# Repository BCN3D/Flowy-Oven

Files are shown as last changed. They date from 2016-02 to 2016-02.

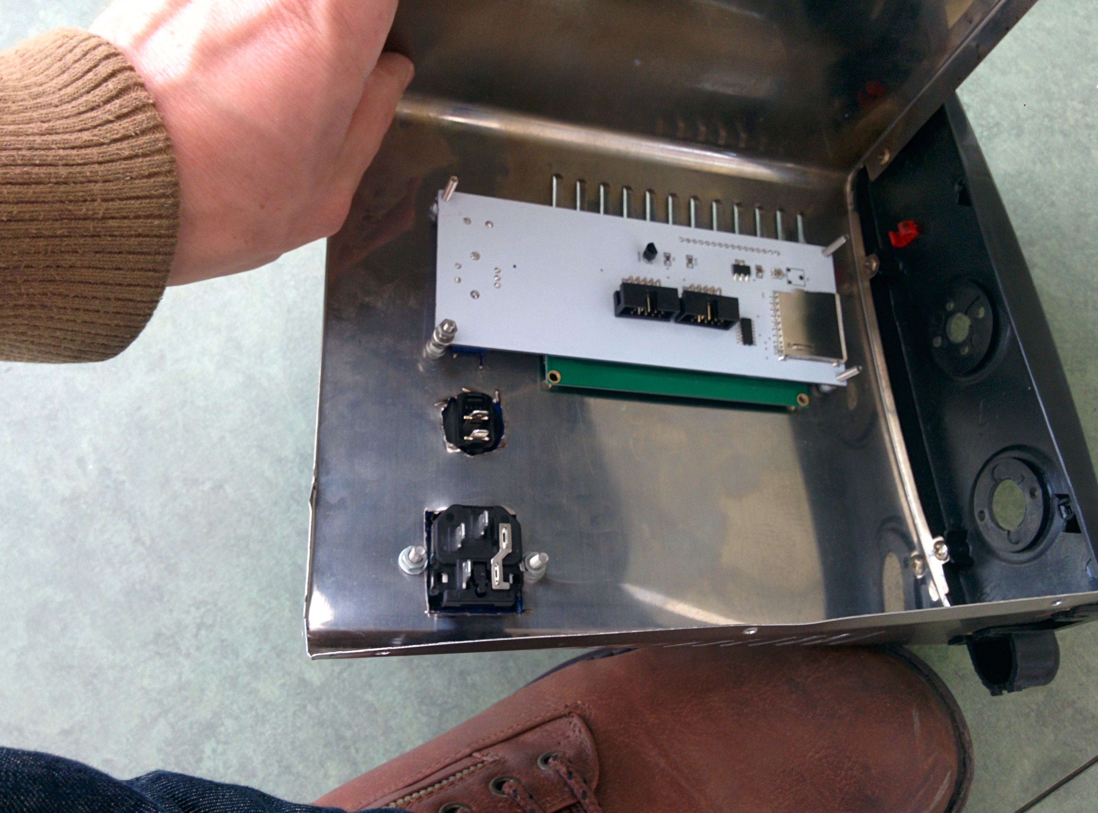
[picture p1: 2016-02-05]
img/IMG_20151126_135709.jpg

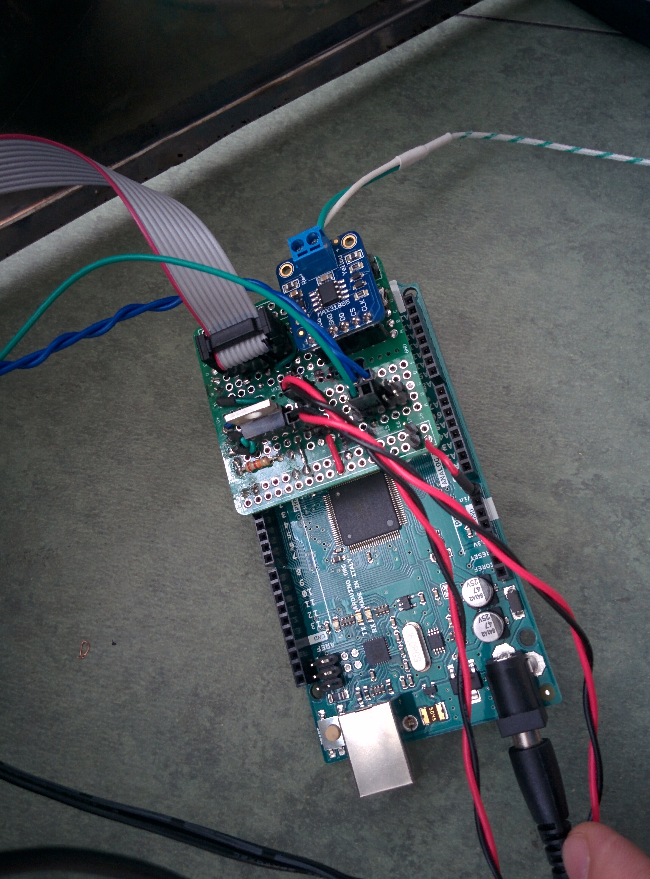
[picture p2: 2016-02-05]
img/IMG_20160113_123603.jpg

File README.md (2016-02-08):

# Flowy Oven
DIY Reflow oven for electronics prototyping.
Here @BCN3DTechnologies we prototype everything quite a lot, and electronics is not an exception.   
That's why we thought we needed a reflow oven. The professional ones are too expensive and we decided to make one by ourselves.   

This Reflow Oven is based on the following projects:
+ [Reflow Oven by Kevin Darrah](http://www.kevindarrah.com/download/arduino_code/ReflowOven_v1.ino)
+ [Reflow Oven by Ben Heck](https://www.youtube.com/watch?v=ckcHyMxqesM)

## Bill of Materials - BOM
+ Reclaimed standard home oven. Ours is about 1KW.
+ Arduino Mega 2560. We have a lot of them laying arround.
+ SSR. Solid State Relay.
+ 16x4 LCD Display with encoder to navigate.
+ Thermocouple breakout board. MAX31855 from adafruit.
+ 12V power supply
+ A fan for cooling the electronics and another to move hot air.
+ Main fused switch, cables and connectors.

## Documents
The following list explains what contains each folder.
+ **src:** where the `Arduino` code lives.
+ **Examples:** Here are also a few examples related to the LCD display and Thermocouple.
+ **Datasheets:** folder to store the Datasheets related to the project.
+ **img:** some pictures of the project.
+ **Printed Parts:** the `CAD` files of the printed parts that we've used to mount the system.

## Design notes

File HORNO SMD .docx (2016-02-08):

HORNO SMD

Descripción del proyecto

Para poder agilizar el proceso de prototipado de placas electrónicas en BCN3D Technologies, hemos decidido implementar nuestras propias herramientas de manera casera.

La primera de estas herramientas es un horno de reflujo. Este horno permite soldar todos los componentes a la vez habiendo colocado previamente todos los componentes encima de la pasta de soldadura.

El horno de reflujo está basado en un horno doméstico para calentar diferentes alimentos. Tiene una potencia de 1000W y dispone de selección de elementos calefactores y temporizador.

Funcionalidades y modificaciones

El horno no solo tiene que ser capaz de llegar a la suficiente temperatura para fundir la pasta de soldadura y soldar los componentes si no que debe de hacerlo siguiendo una curva característica. A continuación se puede ver una gráfica con una curva característica de reflujo:

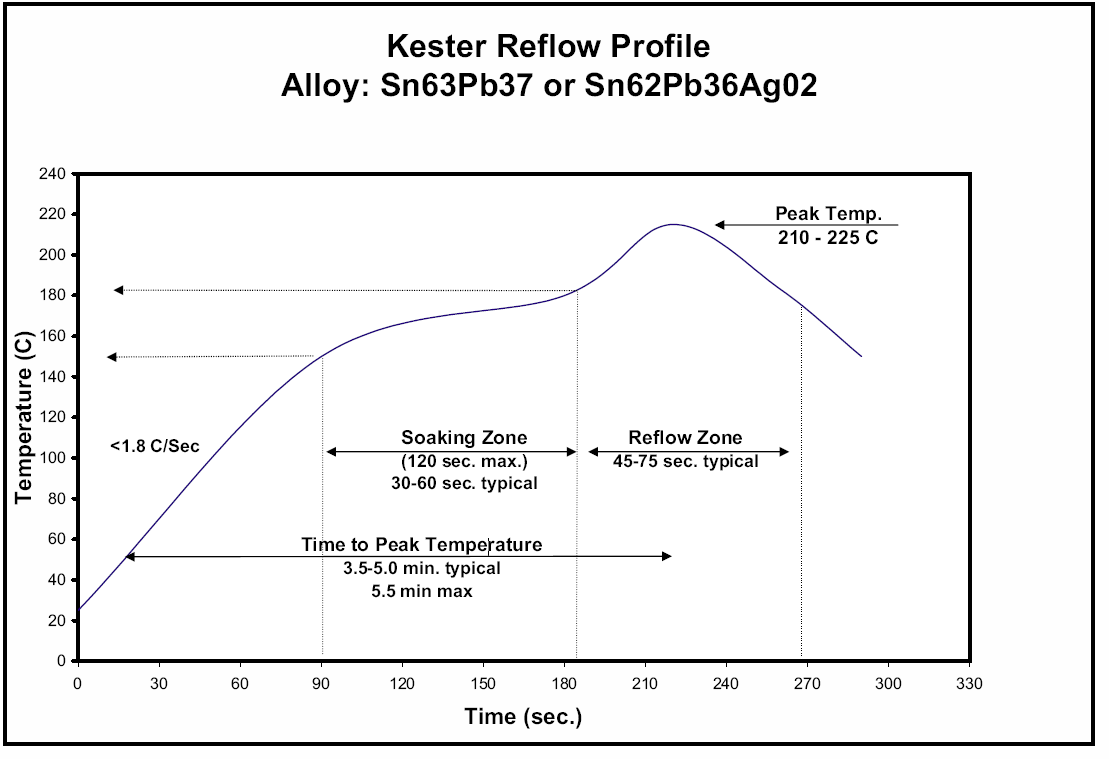
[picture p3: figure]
attachment.php

Lista de materiales

A continuación se presenta la lista de materiales necesarios para completar el proyecto.

Material | Unidades | Enlace | Subtotal | Total
Horno Ariente 1000W | 1
Arduino Mega 2560 | 1
Smart controller LCD | 1
Conector C13 con fusible | 1
MAX31855 | 1
Termopar tipo K | 1
Rele de estado solido KG-25Da | 1
Interuptor | 1
Fuente 12V | 1
Ventiladores | 2
Enchufe C13 con fusible | 1

Módulo de control

El Módulo de control consiste en un Arduino MEGA2560. el arduino controlara el LCD y el relé de estado solido. Analizará la temperatura del interior del horno mediante el modulo modulo max6675 y mantendra la curvatura de reflow necesaria a seguir en el proceso.

Módulo de pantalla “Smart Controller display”

Es un módulo que consta de un LCD de 16x4, un encoder+pulsador, un pulsador y un buzzer.

También tiene un lector de SD, pero no se utilizara en este proyecto. Para navegar entre los menús se utiliza el Encoder y el pulsador del Encoder para poner en marcha el programa seleccionado. El otro pulsador servirá para el para de emergencia y activará el buzzer para avisar de que ha sido pulsado.

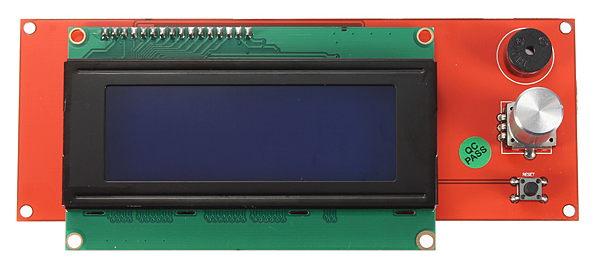
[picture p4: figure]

Módulo sensor de temperatura “MAX6675”

El integrado max31855 digitliza en 12 bits la señal analogica que recibe desde el termopar.

Será alimentado por el arduino. El integrado solo funciona con termopares del tipo K.

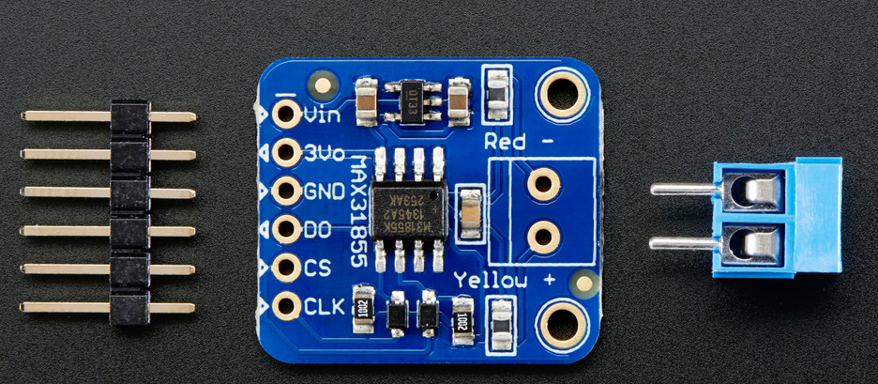
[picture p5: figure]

modulo termopar:

tutorial: https://learn.adafruit.com/thermocouple?view=all

Modulo: http://www.exp-tech.de/adafruit-thermoelement-verstaerker-max31855-breakout-board-max6675-upgrade-v2-0

Termopar: http://www.exp-tech.de/thermocouple-type-k-glass-braid-insulated-k

Prueba LCD + Encoder +Boton+ Buzzer.

Se realiza una pequeña prueba para comprobar que todos los componentes de Smart Controller funcionan correctamente. Cargamos un pequeño programa llamado MENU (esta en la carpeta de programas) en el Arduino Mega 2560 y conectamos los pines corespndientes.

* LCD RS pin va conectado al digital pin 34

* LCD Enable pin conectado al digital pin 32

* LCD D4 pin conectado al digital pin 30

* LCD D5 pin conectado al digital pin 36

* LCD D6 pin conectado al digital pin 28

* LCD D7 pin conectado al digital pin 38

Para usar el Encoder usamos la librería Encoder.h. Los pines del encoder en nuestra aqueta son 15 y 16 de la arduino.

Los dos pulsadores tanto el de Encoder como el de Reset están conectados a 21 y 1 respectivamente.

Buzzer conectado al digital pin 20; Rele conectado al digital pin 17; Ventilador conectado al pin digital 14.

Prueba del Termopar y MAX31885

Para esta prueba usaremos las librerías <SPI.h>; "Adafruit_MAX31855.h" ; <LiquidCrystal.h>. Las librerías esta disponibles en Gihub. Adaptamos los pines de conexión a nuestra placa de siguiente forma:

thermoCLK = 52;

thermoCS = 50;

thermoDO = 48;

Las temperaturas obtenidas se comparan con un termopar digital funcional. Y la diferencia es de pocos grados. El programa modificado que se ha hecho servir esta en la carpeta de PROGRAMAS.

Prueba del Rele de estado Solido SSR.

El rele que utilizamos es KG- 25DA. El programa usado para comprobar su funcionamiento es el “Menu”. El pin de salida es el 7 de la arduino y se pone a 1 cuando se aprieta el pulsador del encoder. Es importante que el relé esté conectado a corriente alterna ya es un Zero-Switching SSR y no se activara si está conectado a DC.

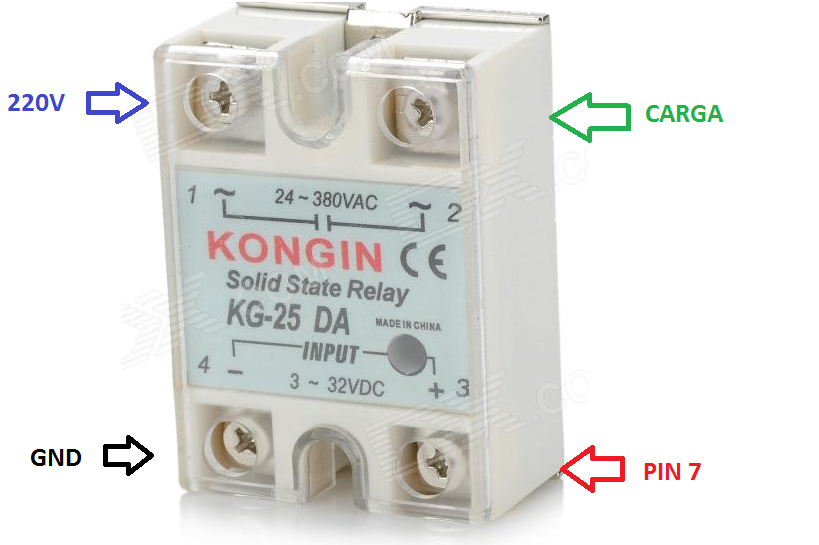
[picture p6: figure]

Programacion

El programa está hecho a base de modificar y adaptar el programa de Kevin Darrah a nuestras necesidades.

http://www.kevindarrah.com/download/arduino_code/ReflowOven_v1.ino

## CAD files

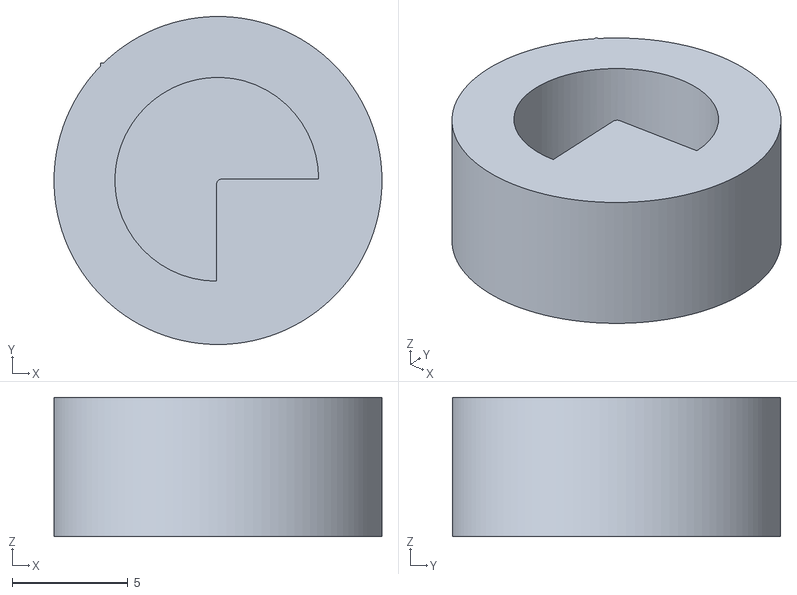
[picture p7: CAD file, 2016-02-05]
Printed Parts/boton_stop_tapa.STL
14.1 x 14.1 x 6.00

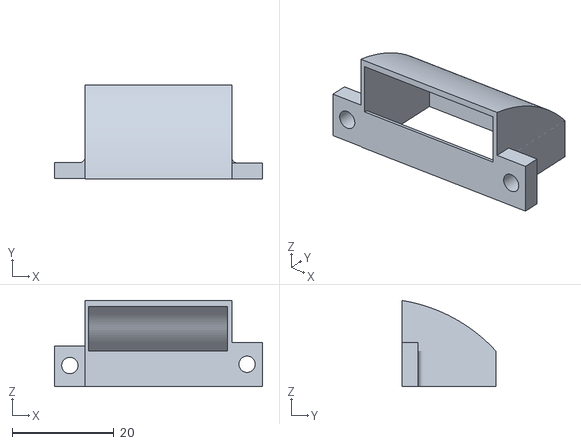
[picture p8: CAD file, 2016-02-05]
Printed Parts/Ventilador.STL
40.9 x 18.4 x 16.9

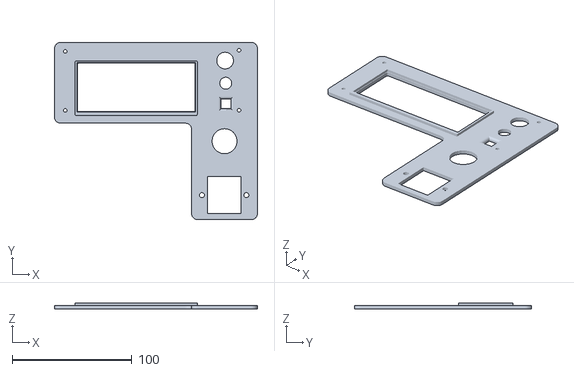
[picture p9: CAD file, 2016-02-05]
Printed Parts/tapa_LCD.STL
169.3 x 147.7 x 5.00

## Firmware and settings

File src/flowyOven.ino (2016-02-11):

// Flowy Oven Project. BCN3DTechnologies - Fundacio CIM
// December 2015 - Marc Cobler, Ostap Petrushchack
// DIY Reflow Oven to solder our own electronics boards.


/* The Circuit:
* LCD RS pin to digital pin 34
* LCD Enable pin to digital pin 32
* LCD D4 pin to digital pin 30
* LCD D5 pin to digital pin 36
* LCD D6 pin to digital pin 28
* LCD D7 pin to digital pin 38
* Reset Button to digital pin 1
* Encoder connected to digital pins  15 y 16
* Buzzer to digital pin 20
* Relay to digital pin 17
* Controlled Fan to digital pin 14
*/

#include <SPI.h>
#include <LiquidCrystal.h>
#include "Adafruit_MAX31855.h" //library MX31855 from adafruit

// Declare the LCD display object
LiquidCrystal lcd(34, 32, 30, 36, 28, 38);//LCD pins

//define Thermocouple pins
#define thermoCLK 52
#define thermoCS 50
#define thermoDO 48

//Define the other pins
#define SSR 17
#define input_switch 21
#define fan1 14
#define buzzer 20

//Define target temperatures and times
#define PREHEAT 130
#define PREHEATDURATION 60000 //1 minute preheating
#define REFLOW 245
#define REFLOWDURATION 30000  //30 seconds reflowing
#define RAMPDOWN 0

// Initialize the Thermocouple
// initialize the library with the numbers of the interface pins
Adafruit_MAX31855 thermocouple(thermoCLK, thermoCS, thermoDO);

//------------------VARIABLES----------------------

// Reflow status strings
String reflow_status[4] = {"press to start","preheat","critical","rampdown"};
// List of tones to play
int tones[] = {261, 277, 294, 311, 330, 349, 370, 392, 415, 440};
//            mid C  C#   D    D#   E    F    F#   G    G#   A}
#define TONESSIZE sizeof(tones)/sizeof(int)
double temperature, old_temperature;
double c;
unsigned long start_time=0, old_time;
unsigned long counter=0;
int setpoint = 0, reflow_stage=0, rate;
int i;
//-------------------------------------------------
void setup()
  {
    //Declare pinModes
    pinMode(SSR, OUTPUT);//solidstate switch
    pinMode(input_switch, INPUT);//switch input
    pinMode(fan1, OUTPUT);//fan
    pinMode(buzzer, OUTPUT);//fan

    digitalWrite(buzzer, LOW);
    //pinMode(1, INPUT);//reset
    //digitalWrite(1,HIGH);

    // Initialize the lcd Screen
    lcd.begin(16, 4);
    lcd.clear();
    lcd.setCursor(5,0);
    lcd.print("BCN3DTech");
    lcd.setCursor(4,1);
    lcd.print("Flowy Oven");

    delay(2500);

    Serial.begin(9600);//for monitoring and logging in processing
    Serial.println("Starting the BCN3DTech Flowy Oven");

    Serial.print("Internal Temp: ");
    Serial.println(thermocouple.readInternal());
    temperature = thermocouple.readCelsius();
    while(isnan(temperature)) {
      Serial.println("Error! Please check and reboot");
      delay(1000);
      temperature = thermocouple.readCelsius();
    }
    Serial.print("Oven temperature: ");
    Serial.println(temperature);

}   // end Setup

void loop(){
  get_temp();
  reflow_update();
  lcd_update();
  heat_control();
  switch_check();
  fan_control();

}//loop

void get_temp(){
  delay(50);     //Calm down the sensor and the reading
  temperature = thermocouple.readCelsius();
  Serial.print("Temp = ");
  Serial.println(temperature);
}// end get temp

void reflow_update(){

  if(reflow_stage==0){//idle   idle   idle
    setpoint=0;//don't do anything
  }//0

  if(reflow_stage==1){//preheat   preheat   preheat
    if(start_time == 0 && temperature>120)//start timer for preheat soak
    start_time=millis();

    setpoint=PREHEAT;//regulate here during preheat
    rate = (temperature-old_temperature)/((millis()-old_time)/1000);//get rate of rise
    if(rate>3)//if rising too fast, kill the setpoint so it slows down
    setpoint=0;

    old_time = millis();//used to find rate
    old_temperature=temperature;

    if((millis()-start_time)>PREHEATDURATION && start_time !=0){//this is where it checks to see if it needs to move on to the next stage
      reflow_stage++;
      start_time=0;}
  }//1
  if(reflow_stage==2){//critical  critical  critical
    if(start_time ==0 && temperature>195 )//start timer during this stage
    start_time=millis();

    setpoint=REFLOW;//regulate here
    rate = (temperature-old_temperature)/((millis()-old_time)/1000);//eh, you can regulate the rate here as well if needed
    if(rate>3)
    setpoint=0;

    old_time = millis();//rate stuff again
    old_temperature=temperature;

    if((millis()-start_time)>REFLOWDURATION && start_time !=0){//how long to stay in
      reflow_stage++;
      start_time=0;}//estaba en 20000
  }//2

   if(reflow_stage==3){//rampdown   rampdown   rampdown
    if(start_time ==0)
    start_time=millis();

    setpoint=0;
    rate = (temperature-old_temperature)/((millis()-old_time)/1000);
    if(rate<-20)//if rate is too fast you can turn heater back on
    setpoint=205;
    old_time = millis();
    old_temperature=temperature;
    if((millis()-start_time)>PREHEATDURATION && start_time !=0){
      reflow_stage=0;
      start_time=0;
      playTone();
    }
  }//3


}// end reflow update

void lcd_update()
  {
    lcd.clear();  //Sets cursor position to zero, zero
    lcd.print("Temp=");
    lcd.print(temperature,1);
    lcd.setCursor(0,1);
    lcd.print("Rate=");
    lcd.print(rate); //show the rate as well
    lcd.print("C/s");
    lcd.setCursor(12,1);
    if (reflow_stage > 0 && reflow_stage < 3) {
      lcd.print("t=");
      lcd.print((millis()/1000)-counter);
      lcd.print("s");
    } else {
      lcd.print("idle");
    }
    lcd.setCursor(4,4);
    lcd.print(reflow_status[reflow_stage]);
}// end lcd_update

void heat_control() {
    if(temperature<setpoint) {
      digitalWrite(SSR, HIGH);
    } else  {
      digitalWrite(SSR,LOW);
    }
}//end heat_control

void switch_check(){//could be better, but it works
  int button = digitalRead(input_switch);
  //int reset = digitalRead(1);
  //if(reset==LOW) digitalWrite(buzzer, HIGH);
  //else digitalWrite(buzzer, LOW);
  if(button==LOW){
    lcd.clear();
    if(reflow_stage>0){
      counter = 0;
      lcd.setCursor(4,1);
      lcd.print("Stopping...");
      reflow_stage=0;
      delay(1000);
    } else  {
      counter = millis()/1000;
      lcd.setCursor(4,1);
      lcd.print("Starting...");
      reflow_stage=1;
    }
    delay(1000);
  }

}// end switch check

void fan_control(){
  if(reflow_stage ==0 || reflow_stage ==3)//keep on continuously if idle or ramping down
  digitalWrite(fan1, HIGH);
  else
  digitalWrite(fan1, LOW);

  if(reflow_stage >0  && reflow_stage <3){//give a little 'love tap' if the temp is higher than the setpoint or if it's ramping quickly
    if(temperature>setpoint || rate>1){
    digitalWrite(fan1, LOW);
    delay(500);
    digitalWrite(fan1,HIGH);}
  }

}// end fan

void playTone() {
  for (size_t i = 0; i < TONESSIZE; i++) {
    tone(buzzer, tones[i]);
    delay(250);
  }
  noTone(buzzer);
}// end playTone

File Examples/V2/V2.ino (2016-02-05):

#include <SPI.h>
#include <LiquidCrystal.h>
LiquidCrystal lcd(8, 9, 10, 11, 12, 13);//LCD pins
#include "Adafruit_MAX31855.h"

int first, second;//temperature variables

String reflow_status[4] = {"press to start","preheat","critical","rampdwn"};
double temperature, old_temperature;
unsigned long start_time=0, old_time;
int setpoint = 0, reflow_stage=0, rate;
int i;
int thermoCLK = 52;
int thermoCS = 53;
int thermoDO = 50;
Adafruit_MAX31855 thermocouple(thermoCLK, thermoCS, thermoDO);
void setup(){
  Serial.begin(9600);
  lcd.begin(16, 2);
  lcd.print("Arduino Reflow");
  digitalWrite(5,HIGH);              //Resistancia de PullUp A1 pulsador
  digitalWrite(6,HIGH);
  pinMode(7, OUTPUT);//solidstate switch
  pinMode(A14, INPUT);//switch input
  pinMode(15, OUTPUT);//fan
  digitalWrite(2, HIGH);//disable max6675
  delay(500);
}//Setup


void loop(){
  get_temp();
  reflow_update();
  lcd_update();
  heat_control();
  switch_check();
  fan_control();
  Serial.println(int(temperature));
  
}//loop

//get temp   get temp   get temp   get temp   get temp   get temp
void get_temp(){
temperature = thermocouple.readCelsius();
}//get temp
//reflow_update  reflow_update  reflow_update  reflow_update  
void reflow_update(){
  
  if(reflow_stage==0){//idle   idle   idle
    setpoint=0;//don't do anything
  }//0
  
  if(reflow_stage==1){//preheat   preheat   preheat
    if(start_time == 0 && temperature>100)//start timer for preheat soak
    start_time=millis();
    
    setpoint=120;//regulate here during preheat
   /* rate = (temperature-old_temperature)/((millis()-old_time)/1000);//get rate of rise
    if(rate>3)//if rising too fast, kill the setpoint so it slows down
    setpoint=0;
    */
    old_time = millis();//used to find rate
    old_temperature=temperature;
    
    if((millis()-start_time)>60000 && start_time !=0){//this is where it checks to see if it needs to move on to the next stage
      reflow_stage++;
      start_time=0;}
  }//1 
  if(reflow_stage==2){//critical  critical  critical
    if(start_time ==0 && temperature>150)//start timer during this stage
    start_time=millis();
    
    setpoint=170;//regulate here
    rate = (temperature-old_temperature)/((millis()-old_time)/1000);//eh, you can regulate the rate here as well if needed
    if(rate>3)
    setpoint=0;
    
    old_time = millis();//rate stuff again
    old_temperature=temperature;
    
    if((millis()-start_time)>20000 && start_time !=0){//how long to stay in
      reflow_stage++;
      start_time=0;}
  }//2
  
   if(reflow_stage==3){//rampdown   rampdown   rampdown
    if(start_time ==0)
    start_time=millis();
    
    setpoint=0;
    rate = (temperature-old_temperature)/((millis()-old_time)/1000);
    if(rate<-20)//if rate is too fast you can turn heater back on
    setpoint=200;
    old_time = millis();
    old_temperature=temperature;
    if((millis()-start_time)>60000 && start_time !=0){
      reflow_stage=0;
      start_time=0;}
  }//3
 
  
}//reflow update
//lcd_update   lcd_update   lcd_update   lcd_update   lcd_update
void lcd_update(){
lcd.clear();
lcd.print("PV=");
lcd.print(temperature);
lcd.print("  ");
lcd.print(rate);//show the rate as well
lcd.setCursor(0,1);
lcd.print(reflow_status[reflow_stage]);
}//lcd_update
// heat_control   heat_control   heat_control   heat_control   
void heat_control(){//starigt forward here
  if(temperature<setpoint)
  digitalWrite(7, HIGH);
  else
  digitalWrite(7,LOW);
}//heat
//switch check   switch check   switch check  switch check
void switch_check(){//could be better, but it works
  if(digitalRead(5)==LOW){
   lcd.clear();
    lcd.print("Starting...");
    reflow_stage=1;
    delay(200);
    }
   if(digitalRead(6)==LOW){
   lcd.clear();
    lcd.print("STOP.");
    reflow_stage=0;
    delay(300);
    }
   
 // }
  
}//switch check
//fan control   fan control   fan control   fan control
void fan_control(){
  if(reflow_stage ==0 || reflow_stage ==3)//keep on continuously if idle or ramping down
  digitalWrite(15, HIGH);
  else
  digitalWrite(15, LOW);
  
  if(reflow_stage >0  && reflow_stage <3){//give a little 'love tap' if the temp is higher than the setpoint or if it's ramping quickly
    if(temperature>setpoint || rate>1){
    digitalWrite(15, HIGH);
    delay(500);
    digitalWrite(15,LOW);}
    
    
  }

}//fan
